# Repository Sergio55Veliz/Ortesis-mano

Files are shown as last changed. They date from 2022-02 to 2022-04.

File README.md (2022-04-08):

# Ortesis dinámica extensora de mano
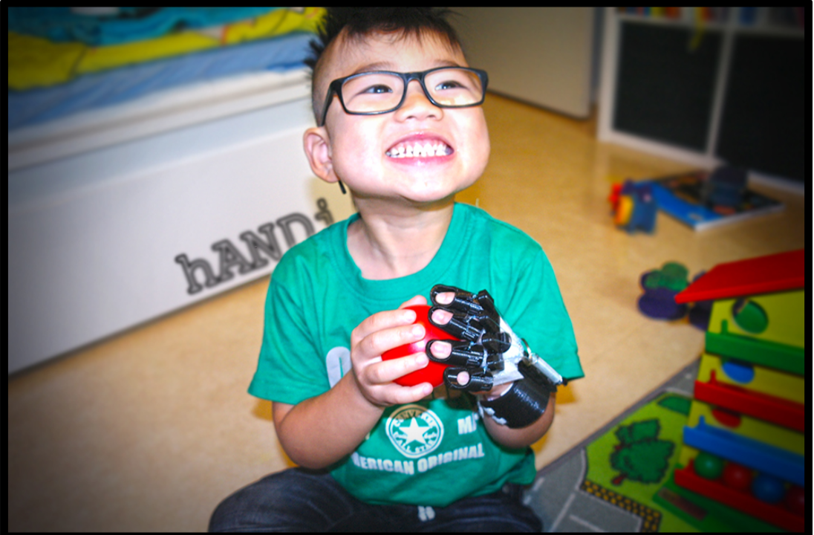
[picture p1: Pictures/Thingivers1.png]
niño

En este repositorio se encuentra la parametrización de una órtesis dinámica extensora para la movilidad de las manos.
El diseño de este sistema esta dirigido a personas con problemas  en las articulaciones o tendones que les impida abrir las manos pero si tengan la capacidad de cerrarlas.
El diseño se lo obtuvo de [Thingiverse](https://www.thingiverse.com/thing:1064647) en el repositorio del usuario Emanuel Teljemo.

# Softwares
Se usaron dos softwares. 
 - `OpenScad`: Un software libre para creación de objetos sólidos CAD por medio de programación, gracias a la programación tenemos control total del diseño de la pieza y podemos crear funciones que dependiendo de lo que se le ingresa, nos da como salida piezas de diferentes medidas.
Esto lo aprovechamos para que al final del desarrollo del código se puedan simplemente ingresar ciertas medidas específicas que debe de tener el sistema para adaptarse a su usuario, siendo así que no hay que diseñar TODO de nuevo para cada paciente. 
 - `Cura`: Programa usado para impresión 3D. Este permite ciertos parámetros de impresión para que puedan ser transformados en código G.

# Funcionamiento
La órtesis permite el movimiento de mano para personas que tienen problemas con abrirla. Esto lo hace gracias a que se usan resortes que sirven para regresar la mano al estado de completamente abierta.
En este caso se usan solamente dos resortes, uno para el pulgar y otro para los demás dedos.

# Materiales

| Elemeto | Cantidad | Figura |
| :--- | :---: | :---: |
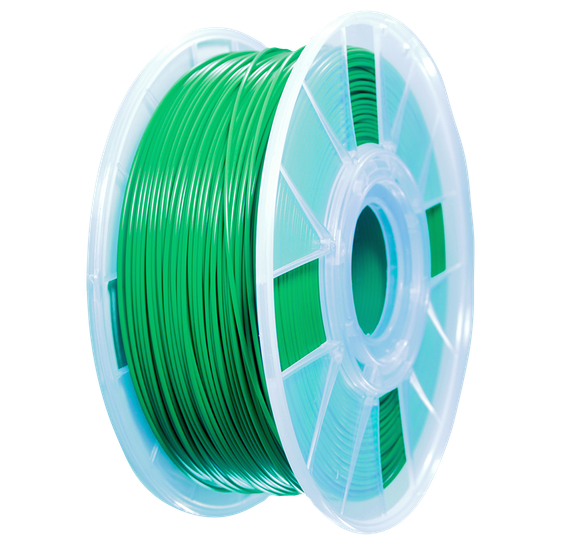
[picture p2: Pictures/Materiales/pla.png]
PLA
| Filamento PLA | 1 |  |
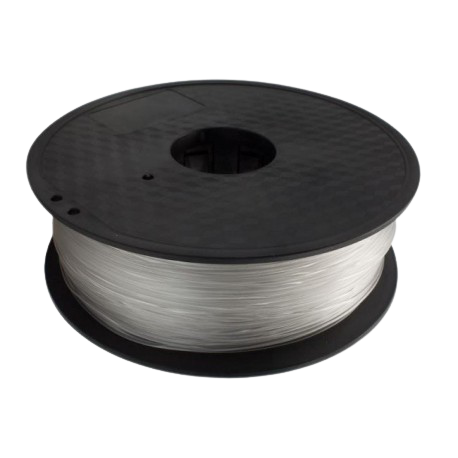
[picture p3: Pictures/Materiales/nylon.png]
nylon
| Hilo de Nylon (no elástico) | 1 |  |
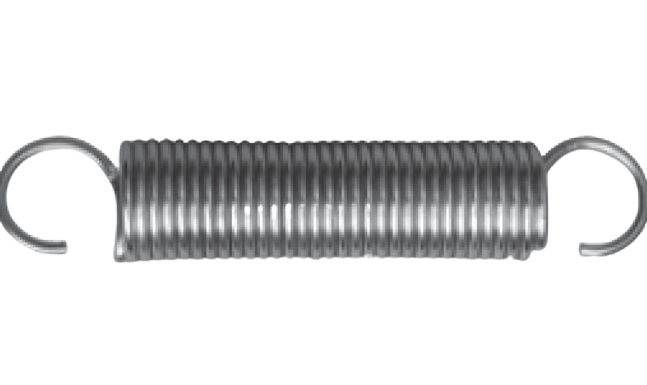
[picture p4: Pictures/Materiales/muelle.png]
muelle
| Resorte o muelle | 2 |  |
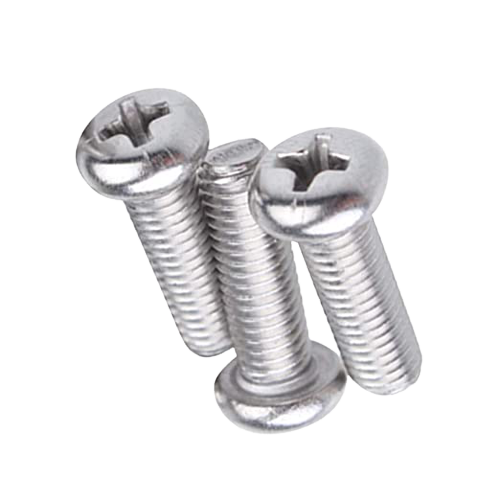
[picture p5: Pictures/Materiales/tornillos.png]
tornillos
| Tornillo M5x10mm <br> Tornillo M5x25mm <br>y sus respectivas tuercas | 6 <br>2 <br> ... |  |
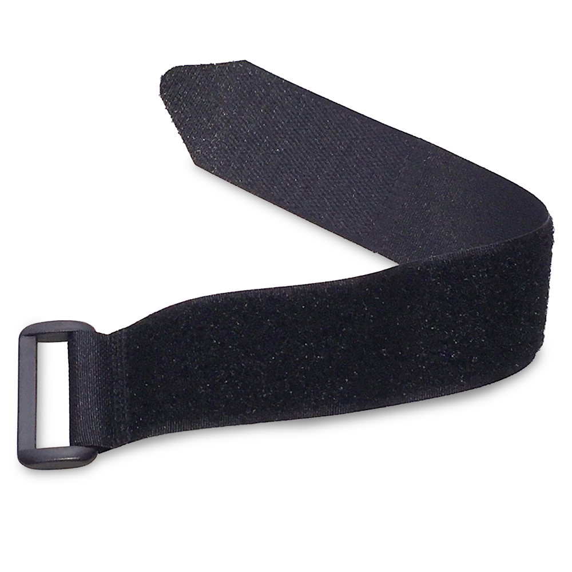
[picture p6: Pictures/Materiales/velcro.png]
velcro
| Velcro | 1 |  |
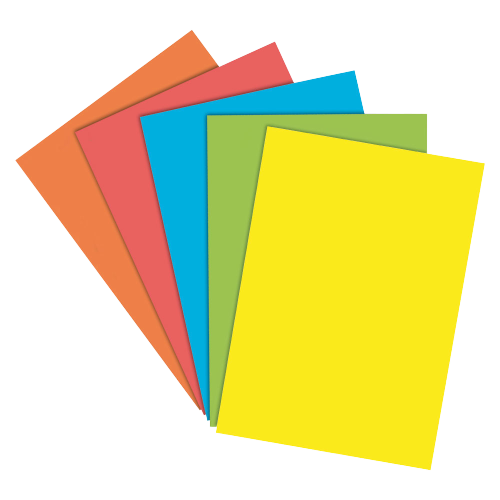
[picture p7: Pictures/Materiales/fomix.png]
fomix
| Fomix | 1 |  |

# Medidas del Paciente
Para la generación de la órtesis en el software OpenScad, se necesitan 7 medidas del antebrazo y mano. A continuación, se hablará de cada una de ellas.

<div align="center">
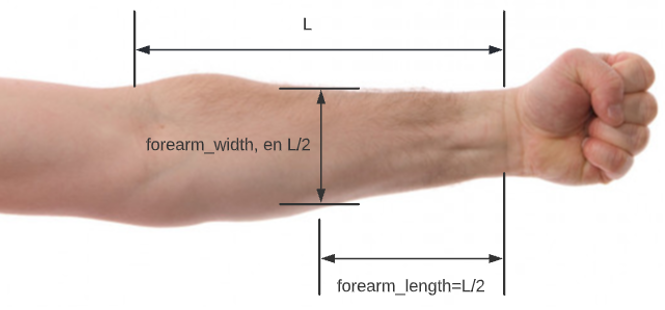
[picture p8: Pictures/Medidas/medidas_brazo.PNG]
medidas_brazo
    
    <p>
        <i>Medidas del antebrazo</i>
    </p>
</div>

Para empezar, se explicarán las dos primeras variables correspondientes a las medidas del antebrazo, como se observa en la figura anterior, se tiene que la variable `forearm_length` es la mitad de la longitud del antebrazo, es decir, L/2. Luego se tiene que `forearm_width` es el ancho del antebrazo, cabe recalcar que dicho ancho será medido en L/2, esto es de suma importancia ya que el antebrazo no tiene un ancho uniforme a lo largo del mismo.

Como recomendación se tiene que a la variable `forearm_width` se le debe sumar 10-12 milímetros aproximadamente (offset) debido a que se utiliza fómix en una pieza para que no lastime la piel del usuario, de forma que reduce el diámetro inicial.

<div align="center">
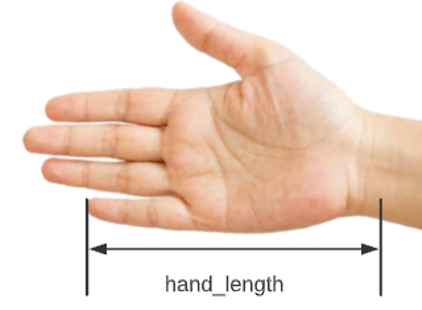
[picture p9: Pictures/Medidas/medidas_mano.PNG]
medidas_mano
    
    <p>
        <i>Medidas de la mano</i>
    </p>
</div>

Para la mano se tendrá una sola variable, la cual se llamará `hand_length`, esta será medida desde la muñeca hasta la parte superior o tope del dedo meñique como se observa en la figura anterior.

<div align="center">
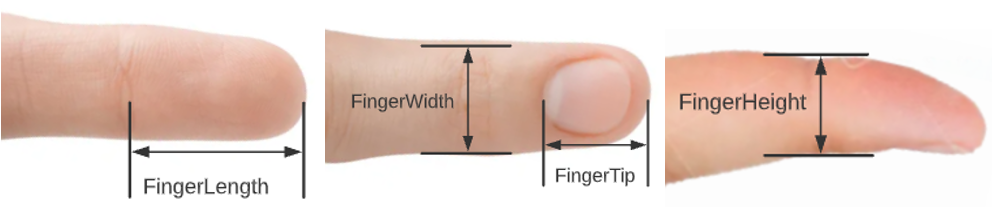
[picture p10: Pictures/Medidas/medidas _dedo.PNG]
medidas_dedo
    
    <p>
        <i>Medidas del dedo</i>
    </p>
</div>

Como se puede observar en la figura anterior, para los dedos se tienen 4 medidas:

- `FingerLength` es medido desde el inicio de la falange distal hasta la punta del dedo
- `FingerWidth` es el ancho del dedo en la zona de la articulación interfalángica distal
- `FingerTip` es medido desde el nacimiento de la uña hasta la punta del dedo
- `FingerHeight` es el alto del dedo en la zona de la articulación interfalángica distal

Cabe recalcar que este proceso de medición se debe de realizar para los cinco dedos de la mano.

# Piezas generadas
Las piezas a generar son 11:
| Pieza | Descripción | Cantidad | Figura |
| :--- | :--- | :---: | :---: |
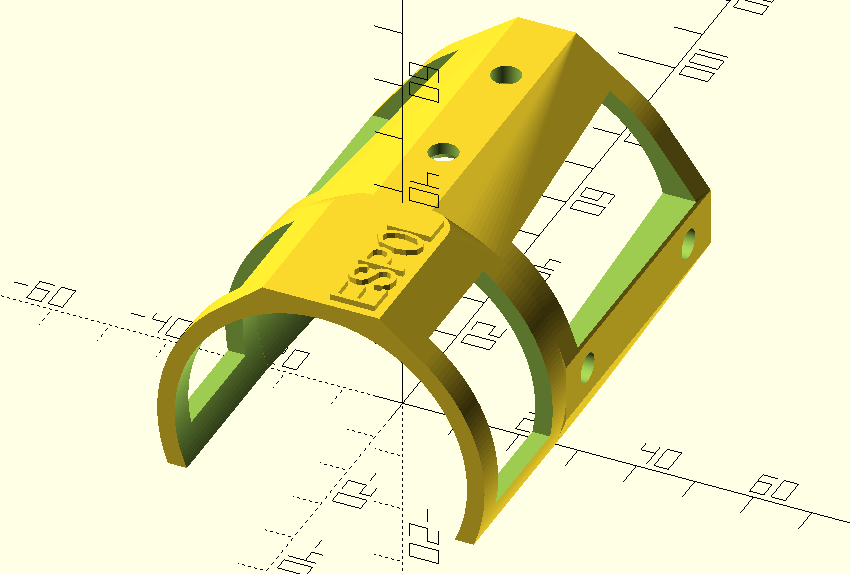
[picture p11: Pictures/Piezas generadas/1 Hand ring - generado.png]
pieza1
| [Hand ring](ortesis_openscad/ORTESIS.scad#L55) | - | 1 |  |
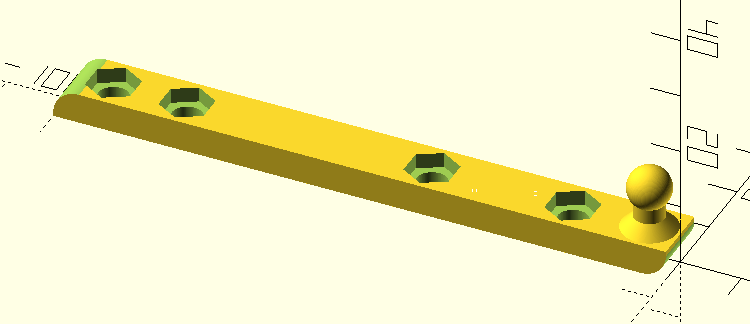
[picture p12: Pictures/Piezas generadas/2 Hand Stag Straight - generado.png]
pieza2
| [Hand Stag Straight](ortesis_openscad/ORTESIS.scad#L263) | - | 1 |  |
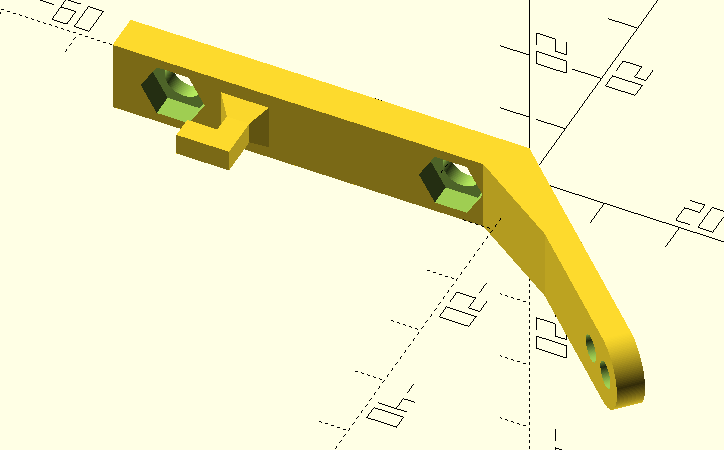
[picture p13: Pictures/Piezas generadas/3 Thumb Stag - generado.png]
pieza3
| [Thumb Stag](ortesis_openscad/ORTESIS.scad#L444) | - | 1 |  |
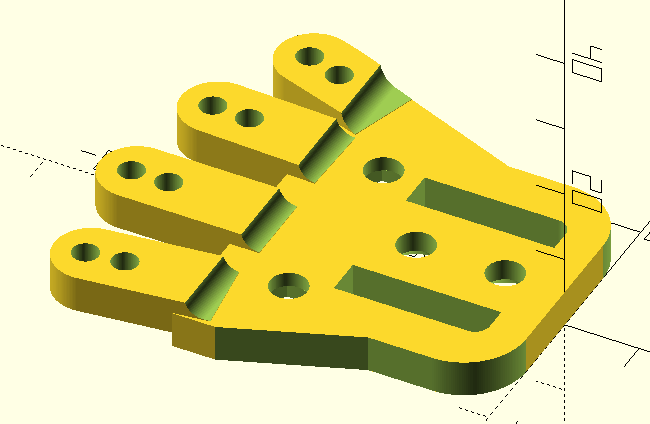
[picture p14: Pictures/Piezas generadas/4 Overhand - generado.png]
pieza4
| [Overhand](ortesis_openscad/ORTESIS.scad#L221) | - | 1 |  |
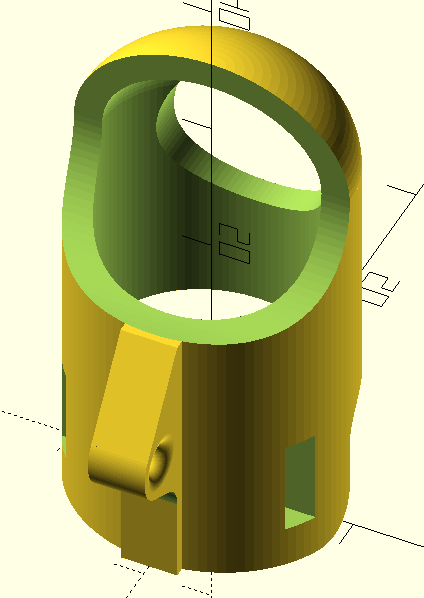
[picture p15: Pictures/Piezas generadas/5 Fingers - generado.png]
pieza5
| [Fingers](ortesis_openscad/ORTESIS.scad#L532) | - | 5 |  |
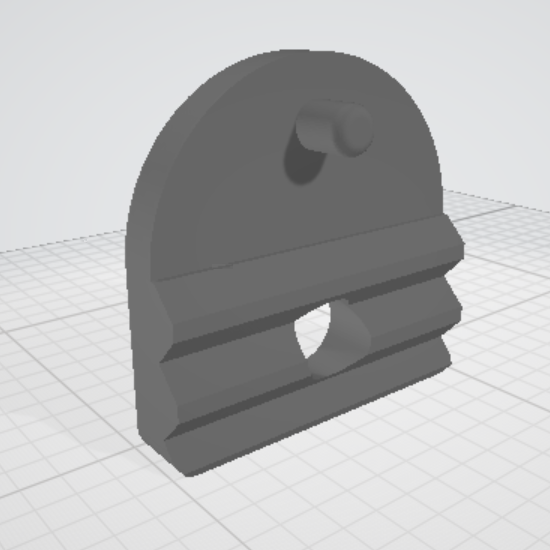
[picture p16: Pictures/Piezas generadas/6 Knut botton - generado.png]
pieza6
| [Knut botton](ortesis_openscad/Knut_1_0_bottom_m4nut.stl) | - | 1 |  |
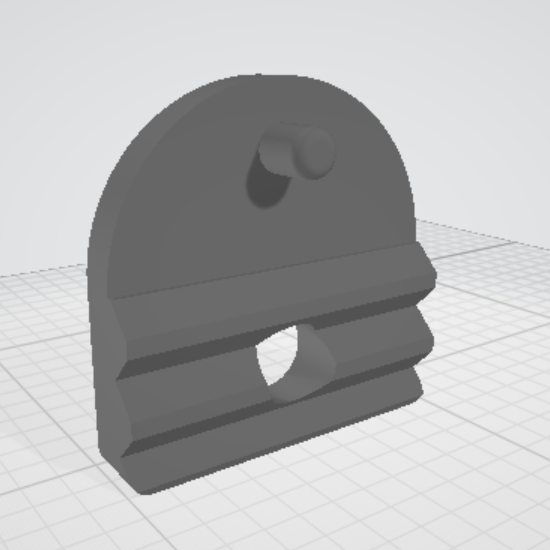
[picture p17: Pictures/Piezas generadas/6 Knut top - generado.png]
pieza7
| [Knut top](ortesis_openscad/Knut_1_0_top_plug4mm.stl) | - | 1 |  |

Como vemos en la tabla, las primeras 5 piezas mencionadas las podemos obtener del archivo OpenScad que programamos, pero las últimas 2 piezas no son parametrizadas. Esas son piezas que no deben de ser modificadas proporcionadas por 
Emanuel Teljemo de su repositorio en [Thingiverse](https://www.thingiverse.com/thing:1064647).

Para generar las piezas, Se deben de seguir los siguientes pasos:
 1. Tomarle las medidas necesarias al paciente e ingresar los parámetros especificados en el archivo `ORTESIS.scad` desde la [línea 13 a la 34](ortesis_openscad/ORTESIS.scad#L13)
 2. Especificar si es para la mano derecha o la izquierda [(línea 10)](ortesis_openscad/ORTESIS.scad#L10)
 3. Especificar qué pieza se quiere generar [(línea 6)](ortesis_openscad/ORTESIS.scad#L6)
 4. Repetir el 3er paso para todas las piezas.

# Configuración del Software de impresión
Se utilizó el software Cura para la impresión, pero básicamente todos se pueden configurar con los mismos parámetros especificados. Los parámetros de impresión utilizados para la impresión son los siguientes:

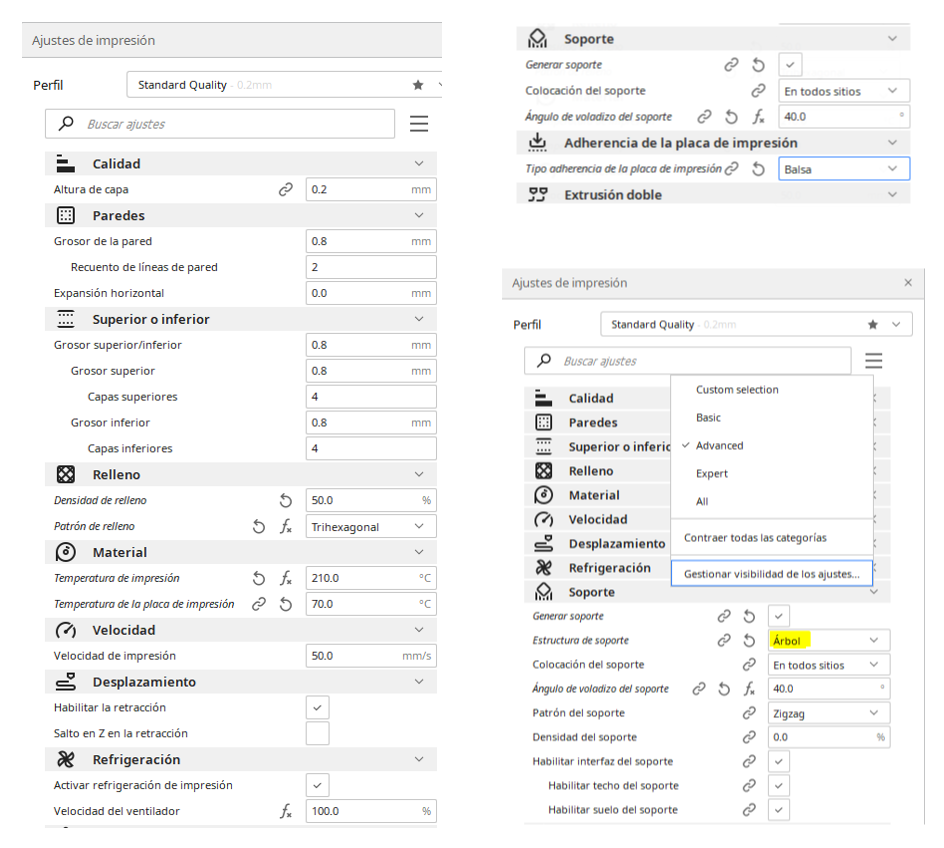
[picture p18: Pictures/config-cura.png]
conf_cura


<br><br><br>

# Ensamblaje del las piezas impresas

# Recomendaciones
 - Para la **generación del archivo STL** de la pieza **‘hand ring’** se debe de aumentarle un offset ya que se utiliza fómix en el interior de dicha pieza para que no lastime la piel del usuario, lo que causa que el diámetro inicial sea menor. El valor recomendado es de 10 a 12 mm de más.
 - **Para** la realizar la **compra del resorte**, se debe de tener en cuenta que la fuerza y largo de dicho resorte debe ser el apropiado para el usuario. De forma general, para manos grandes se necesita más fuerza y largo, y para manos pequeñas se utiliza resortes no tan fuertes y no tan largos. Si se utilizan resortes en los que se deba de aplicar demasiada fuerza esto puede generar que se le corte la circulación al paciente.
 - Para colocar los **hilos de nylon** en la órtesis, se debe de cortar de forma correcta el largo de los hilos, ya que si es muy largo no podrá estirar los dedos, y si es muy corto, los estirará mucho.
 - Es importante verificar que los **tornillos lleguen al tope** de la unión de dos piezas, debido a que los resortes pueden chocar con el exceso del tornillo si este es muy largo, por ende, se recomienda utilizar tornillos de 5 mm de diámetro y 10 mm de alto, a excepción de la pieza ‘Knut’.
 - Se recomienda cambiar el tipo de soporte convencional a tipo árbol para la **impresión de los Fingers** ya que facilita el despegue del material de soporte.
 - Para la **medición e impresión de los dedos**, será un proceso iterativo debido a que cada persona tiene diferentes tipos de dedos (anchos, flacos, largos), por eso, es importante mencionar que cada dedo tendrá un **offset** en particular para que al usuario no le quede ni tan suelto o ajustado. Se recomienda sumarle entre 1 y 1.5 mm a las medidas que uno realiza y seguir iterando hasta tener las medidas correctas.
 - Se recomienda utilizar un calibrador vernier para medir las variables necesarias para la creación de la órtesis, en la medición de la longitud del largo del antebrazo (L) se puede utilizar una cinta métrica o una regla de 30 cm si es posible. En caso de usar el calibrador, es mejor si tiene acoplado un material para alargar la mordaza fija, esto permitiría medir de mejor forma el largo de los dedos.

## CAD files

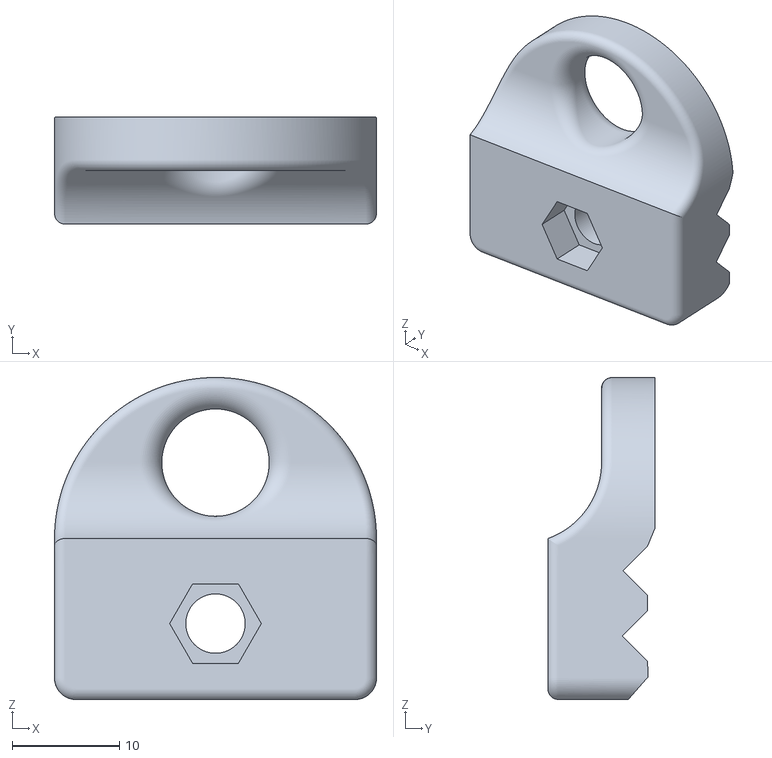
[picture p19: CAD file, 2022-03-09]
Knut_1_0_bottom_m4nut.stl
30.0 x 10.0 x 30.0

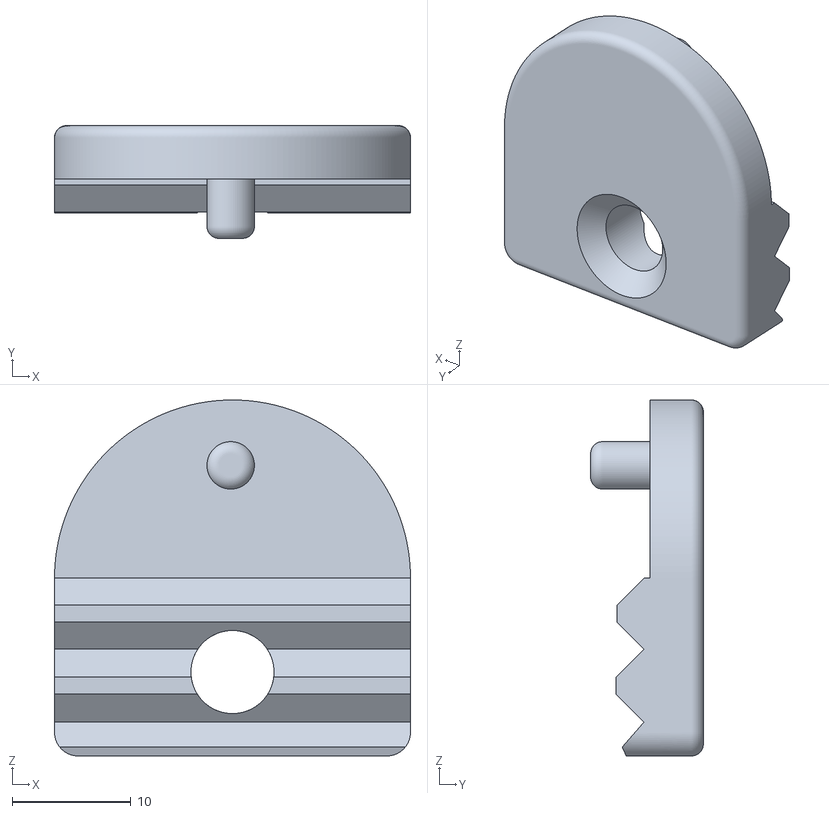
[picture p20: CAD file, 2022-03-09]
Knut_1_0_top_plug4mm.stl
30.0 x 9.50 x 30.0

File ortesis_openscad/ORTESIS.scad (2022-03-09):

//Se importa una librería para colocar nombres en el sólido
use <write.scad>

//Puede escribir las siguientes opciones:
//Número 1: soporte antebrazo, Número 2: soporte mano, Número 3: mano, Número 4: soporte pulgar, Número 5: dedo   
pieza= 1;

//Puede escribir las siguientes opciones para el tipo de brazo-mano:
//derecha, izquierda
mano="derecha";
// Unidades [mm] 

// mitad de la longitud del antebrazo
forearm_length=83; //min valor 83mm

//ancho del antebrazo, generalmente es medido en la mitad de la longitud del antebrazo
forearm_width=50; //min valor 50mm



//Longitud medida desde la muñeca hasta el tope del dedo meñique
hand_length=77; //Valor min 77

//Ancho del dedo
FingerWidth = 15.5;
//Alto del dedo
FingerHeight = 13.5;
//largo del dedo
FingerLength = 23.5;
//Largo del orificio de la uña del dedo
FingerTip = 12;

//Grosor del material para los dedos, valor recomendado!!!
Thikness = 2;




ancho_forearm_p=forearm_width/50;
valor1=hand_length/1.73033707865;
valor_p=valor1/44.5;

//largo de la parte donde se coloca el nombre "ESPOL"
largo1=round(forearm_length/2.77);

//Largo de la parte que va a ir con los tornillos
largo2=forearm_length-largo1;

valor=largo2/0.95495495495;
//El desfase vertical es la distancia que se eleva el sólido ya que no es semi-circunferencia para tener un "mejor" agarre
desfase_vertical= forearm_width/5;


//********************************************************
// Código del soporte del antebrazo

// Sólido donde se coloca el nombre
module soporte_nombre(){
    difference(){
        translate([0,-largo1/2, (forearm_width+6)/2 +desfase_vertical-forearm_width/50])
        cube([forearm_width/2.5,largo1,forearm_width/25],center=true);
            
        translate([-forearm_width/5,0,(forearm_width+6)/2 +desfase_vertical-forearm_width/25])
        empalme(5,forearm_width/10,0,0,0);
            
        translate([forearm_width/5,0,(forearm_width+6)/2 +desfase_vertical-forearm_width/25])
        rotate([0,0,270])
        empalme(5,forearm_width/10,0,0,0);
    }
}

// Primer Soporte del antebrazo (donde se coloca el nombre "ESPOL")
module soporte1(){
    difference(){
        hull(){
            translate([0,0,desfase_vertical])
            rotate([90,0,0])
            cylinder(h=largo1,d=forearm_width+6,$fn=200);
                
            soporte_nombre();
        }  
        translate([0,0.5,desfase_vertical])
        rotate([90,0,0])
        cylinder(h=largo1+1,d=forearm_width,$fn=200);
            
        translate([0,-largo1/2,forearm_width/2.63])
        cube([forearm_width+20,largo1/1.5,forearm_width/1.79],center=true);
    }
    translate([forearm_width/5 -1.5,-largo1+1.5,(forearm_width+6)/2 +desfase_vertical])
    rotate([0,0,90])
    write("ESPOL",t=1,h=largo1/4);
}


// Con difference se puede hacer empalme a un solido
module empalme(radio,largo,inclinacionX,inclinacionY,inclinacionZ){
    diam=radio*2;
    scale([1.05,1.05,1.05])
    translate([radio,-radio,0])
    rotate([inclinacionX,inclinacionY,inclinacionZ])
    linear_extrude(largo){
        difference(){
            square(diam,center=true);
            circle(d=diam,$fn=200);
            scale([1.1,1.1,1.1])
            polygon(points=[[0,radio],[radio,radio],[radio,-radio],[-radio,-radio],[-radio,0],[0,0]]);
        }
    }
}



// Empalme 2. Por el momento no se lo utiliza en este proyecto
module empalme2(diam, diam_circ){
    //Cambiar el valor 10
    translate([0,diam/2,10])
    rotate([90,0,0])
    rotate_extrude($fn=150)
    translate([diam_circ/2+diam/2,0,0])
    union(){
        polygon(points=[[0,diam/2],[diam/2,diam/2],[diam/2,-diam/2
            ],[-diam/2,-diam/2],[-diam/2,0],[0,0]]);
        circle(d=diam,$fn=150);
    }
}

// Soporte para colocar los tornillos laterales
module agarres_laterales(){
    difference(){
        translate([-(forearm_width+6)/2,0,forearm_width/10])
        cube([4,largo2,desfase_vertical]);
        translate([-(forearm_width+6)/2+2,0,forearm_width/10])
        cube([4,largo2/2,desfase_vertical]);
    }
}

// Soporte para colocar los tornillos superiores
module agarre_superior(){
    difference(){
        translate([0,largo2/2,(forearm_width+6)/2 +desfase_vertical-2.5])
        rotate([0,90,0])
        cube([5,largo2,desfase_vertical],center=true);
        translate([0,largo2/2,(forearm_width+6)/2 +desfase_vertical-5])
        rotate([0,90,0])
        cube([5,largo2,desfase_vertical],center=true);
    }
}

// Huecos para los tornillos
module huecos_tornillos(inclinacionX,inclinacionY,inclinacionZ){
    rotate([inclinacionX,inclinacionY,inclinacionZ])
    union(){
        translate([0,0,2])
        cylinder(h=5,d=5,$fn=200);
        cylinder(h=2.1,d1=9,d2=5,$fn=200);
    }
}

// Se colocan los huecos de los tornillos en las partes laterales
module huecos_laterales(){
    translate([forearm_width/2 -0.9,largo2/6.752,desfase_vertical])
    huecos_tornillos(0,90,0);
    translate([forearm_width/2 -2.8,largo2/1.183,desfase_vertical])
    huecos_tornillos(0,90,0);
}

// Se colocan los huecos de los tornillos en la parte superior
module huecos_superiores(){
    translate([0,largo2/3.533,forearm_width/2 +desfase_vertical-1.2])
    huecos_tornillos(0,0,0);
    translate([0,largo2/1.3947,forearm_width/2 +desfase_vertical-2.3])
    huecos_tornillos(0,0,0);
}

//Segundo Soporte donde se colocan los tornillos, todas las anteriores funciones unidas
module soporte2(){
    difference(){
        union(){
            difference(){
                hull(){
                    rotate([90,0,0])
                    translate([0,desfase_vertical,-largo2/2])
                    cylinder(h=largo2,d2=forearm_width+6,d1=forearm_width+1,$fn=200, center=true);
                    agarre_superior();
                    agarres_laterales();
                    mirror([1,0,0])
                    agarres_laterales();
                }
                rotate([90,0,0])
                translate([0,desfase_vertical,-largo2/2])
                cylinder(h=largo2 +1,d2=forearm_width,d1=forearm_width-5,$fn=200, center=true);
                    
                translate([0,largo2/2,forearm_width/2.08])
                cube([forearm_width+20,largo2-9.52,forearm_width/3],center=true);   
            }
        }
        huecos_laterales();
        mirror([1,0,0])
        huecos_laterales();
        huecos_superiores();
    }
}


//Ensamble de la pieza final
module soporte_antebrazo(){
    difference(){
        union(){
            soporte1();
            soporte2();
        }
        translate([0,0,-forearm_width/5])
        cube([forearm_width+10,forearm_length+100,forearm_width/2.5],center=true); 
    }
}




//********************************************************
//Código soporte mano

module base_soporte(largo,ancho, espesor){
    scale([1,ancho_forearm_p,1])    
    translate([-largo/2,0,espesor/2])
    cube([largo,ancho,espesor],center=true);
}

module soporte_resorte(){
    union(){ 
        translate([0,0,2])
        cylinder(h=5,d=5,$fn=200);
        cylinder(h=2.1,d1=9,d2=5,$fn=200);
        translate([0,0,7])
        sphere(d=7,$fn=120);
    }
}

module soporte_tuerca(){
    rotate([0,0,90])
    union(){
        cylinder(h=2.5,d=8.5,$fn=6,center=true);
        cylinder(h=20,d=5,$fn=120,center=true);
    }
}

module empalme(radio,largo,inclinacionX,inclinacionY,inclinacionZ){
    diametro=radio*2;
    translate([0,0,-1])
    scale([1.05,1.05,1.05])
    translate([radio,-radio,0])
    rotate([inclinacionX,inclinacionY,inclinacionZ])
    linear_extrude(largo){
        difference(){
            square(diametro,center=true);
            circle(d=diametro,$fn=200);
            scale([1.1,1.1,1.1])
            polygon(points=[[0,radio],[radio,radio],[radio,-radio],[-radio,-radio],[-radio,0],[0,0]]);
        }
    }
}

module hand_stag_straight(){
    difference(){
        union(){
            base_soporte(valor,10,5);
            translate([-valor,0,0])
            base_soporte(valor1,10,5);
            translate([-5,0,5])
            soporte_resorte();
        }
        translate([-8.4,-25,5.2])
        empalme(4,50,90,270,180);

        mirror([1,0,0])
        translate([-8.4+valor+valor1,30,1.8])
        empalme(4,50,90,90,0);

        translate([-valor/3.171428571,0,3.75])
        soporte_tuerca();
        translate([-valor/1.37037037,0,3.75])
        soporte_tuerca();

        translate([-valor-valor1/1.78,0,3.75])
        soporte_tuerca();
        translate([-valor-valor1/1.202702703,0,3.75])
        soporte_tuerca(); 
    }
}


//********************************************************
//Código mano
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

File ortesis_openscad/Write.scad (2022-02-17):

/* 	Version 3
	Added support for font selection (default is Letters.dxf)
	Added WriteCube module
	Added Rotate for text (rotates on the plane of the text)
	Added writesphere
	Added space=     (spacing between characters in char widths) def=1
	Added writecylinder()

 By Harlan Martin
 harlan@sutlog.com
 January 2012

 (The file TestWrite.scad gives More usage examples)
 (This module requires the file Letters.dxf to reside in the same folder)
 (The file Letters.dfx was created with inkscape..Each letter is in its own layer)
 (This module seperates each letter in the string and imports it from Letters.dfx)
 
*/

	pi=3.1415926535897932384626433832795028841971693993751058209;
	pi2=pi*2;


// These control the default values for write() writesphere() writecube()
// if the parameters are not included in the call. Feel free to set your own
// defaults.

//default settings
	center=false;
	h = 4;			 //mm letter height
	t = 1; 			//mm letter thickness
	space =1; 			//extra space between characters in (character widths)
	rotate=0;			// text rotation (clockwise)
	font = "Letters.dxf";	//default for aditional fonts


// write cube defaults
	face = "front";	 // default face (top,bottom,left,right,back,front)
	up =0;		 //mm up from center on face of cube
	down=0;
	right =0;		 //mm left from center on face of cube
	left=0;		
	

// write sphere defaults
	rounded=false;	 //default for rounded letters on writesphere
	north=0; 		// intial text position (I suggest leave these 0 defaults)
	south=0;
	east=0;
	west=0;
	spin=0;
// writecylinder defaults
	middle=0;     //(mm toward middle of circle)
	ccw=false;   //write on top or bottom in a ccw direction
 	r1=0; 	//(not implimented yet)
	r2=0;	 	//(not implimented yet)
	


// Contact me if your interested in how to make your own font files
// Its tedious and time consuming, but not very hard


module writecylinder(text,where,radius,height){
	wid=(.125* h *5.5 * space);
	widall=wid*(len(text)-1)/2; 
	//angle that measures width of letters on sphere
	function NAngle(radius)=(wid/(pi2*radius))*360;
	//angle of half width of text
	function mmangle(radius)=(widall/(pi2*radius)*360);
	
	if ((face=="top")||(face=="bottom") ){
		if (face=="top" ){
			if (center==true){
				writecircle(text,where+[0,0,height/2],radius-h,rotate=rotate,font=font,h=h,t=t,
				space=space,east=east,west=west,middle=middle,ccw=ccw);
			}else{
				writecircle(text,where+[0,0,height],radius-h,rotate=rotate,font=font,h=h,t=t,
				space=space,east=east,west=west,middle=middle,ccw=ccw);
			}
		}else{
			rotate(180,[1,0,0])
			if (center==true){
				writecircle(text,where+[0,0,height/2],radius-h,rotate=rotate,font=font,h=h,t=t,
				space=space,east=east,west=west,middle=middle,ccw=ccw);
			}else{
				writecircle(text,where+[0,0,0],radius-h,rotate=rotate,font=font,h=h,t=t,
				space=space,east=east,west=west,middle=middle,ccw=ccw);
			}
		}
	
	}else{
        if (center==true)  {
            rotate(-mmangle(radius)*(1-abs(rotate)/90),[0,0,1])
            translate(where)
            writethecylinder(text,where,radius,height,r1=radius,r2=radius,h=h,
                rotate=rotate,t=t,font=font,face=face,up=up,down=down,
                east=east,west=west,center=center,space=space,rounded=rounded);
        } else{
            rotate(-mmangle(radius)*(1-abs(rotate)/90),[0,0,1])
            translate(where+[0,0,height/2])
                writethecylinder(text,where,radius,height,r1=radius,r2=radius,h=h,
                rotate=rotate,t=t,font=font,face=face,up=up,down=down,
                east=east,west=west,center=center,space=space,rounded=rounded);
        }
	}
}
module writecircle(text,where,radius){
	wid=(.125* h *5.5 * space);
	widall=wid*(len(text)-1)/2;
	//angle that measures width of letters on sphere
	function NAngle(radius)=(wid/(pi2*radius))*360;
	//angle of half width of text
	function mmangle(radius)=(widall/(pi2*radius)*360);	
	
	if (ccw==true){
		rotate(-rotate+east-west,[0,0,1]){
			rotate(-mmangle(radius-middle),[0,0,1]){
			translate(where)
				for (r=[0:len(text)-1]){
					rotate(-90+r*NAngle(radius-middle),[0,0,1]) // bottom out=-270+r 
					translate([radius-middle,0,0])
					//rotate(90,[1,0,0])
					//rotate(90,[0,1,0])
					rotate(-270,[0,0,1])  // flip text (botom out = -270)
					write(text[r],center=true,h=h,t=t,font=font);
				}
			}
		}
	}else{
		rotate(-rotate-east+west,[0,0,1]){
			rotate(mmangle(radius-middle),[0,0,1]){
			translate(where)
				for (r=[0:len(text)-1]){
					rotate(90-r*NAngle(radius-middle),[0,0,1]) // bottom out=-270+r 
					translate([radius-middle,0,0])
					//rotate(90,[1,0,0])
					//rotate(90,[0,1,0])
					rotate(270,[0,0,1])  // flip text (botom out = -270)
					write(text[r],center=true,h=h,t=t,font=font);
				}
			}
		}		
	}

}
module writethecylinder(text,where,radius,height,r1,r2){
	wid=(.125* h *5.5 * space);
	widall=wid*(len(text)-1)/2; 
	//angle that measures width of letters on sphere
	function NAngle(radius)=(wid/(pi2*radius))*360*(1-abs(rotate)/90);
	//angle of half width of text

	function mmangle(radius)=(widall/(pi2*radius)*360);
			translate([0,0,up-down])
			rotate(east-west,[0,0,1])
			for (r=[0:len(text)-1]){
				rotate(-90+(r*NAngle(radius)),[0,0,1])
				translate([radius,0,-r*((rotate)/90*wid)+(len(text)-1)/2*((rotate)/90*wid)])
				rotate(90,[1,0,0])
				rotate(90,[0,1,0])
				write(text[r],center=true,h=h,rotate=rotate,t=t,font=font);
		//echo("zloc=",height/2-r*((rotate)/90*wid)+(len(text)-1)/2*((rotate)/90*wid));
			}

}


module writesphere(text,where,radius){
	wid=(.125* h *5.5 * space);
	widall=wid*(len(text)-1)/2;
	
	echo("-----------------",widall,wid,mmangle(radius));
	//angle that measures width of letters on sphere
	function NAngle(radius)=(wid/(pi2*radius))*360;
	//angle of half width of text
	function mmangle(radius)=(widall/(pi2*radius)*360);	

	rotate(east-west,[0,0,1]){
	rotate(south-north,[1,0,0]){
	rotate(spin,[0,1,0]){
	rotate(-mmangle(radius),[0,0,1]){
		if ( rounded== false ){
			translate(where)
			for (r=[0:len(text)-1]){
				rotate(-90+r*NAngle(radius),[0,0,1])
				translate([radius,0,0])
				rotate(90,[1,0,0])
				rotate(90,[0,1,0])
				write(text[r],center=true,h=h,rotate=rotate,t=t,font=font);
			}
		}else{
			difference(){
				translate(where)
				for (r=[0:len(text)-1]){
					rotate(-90+r*NAngle(radius),[0,0,1])
					translate([radius,0,0])
					rotate(90,[1,0,0])
					rotate(90,[0,1,0])
					write(text[r],center=true,h=h,rotate=rotate,t=t*2+h,font=font);
				}
				difference(){ //rounded outside
					sphere(radius+(t*2+h)*2);
					sphere(radius+t/2);
				}
				sphere(radius-t/2); // rounded inside for indented text
			} 
		}
	}}}}
}


module writecube(text,where,size){
	if (str(size)[0] != "["){  
		// its a square cube (size was not a matrix so make it one)
		writethecube(text,where,[size,size,size],h=h,rotate=rotate,space=space,
		t=t,font=font,face=face,up=up,down=down,right=right,left=left);

	}else{
		// its not square
		writethecube(text,where,size,h=h,rotate=rotate,space=space,
		t=t,font=font,face=face,up=up,down=down,right=right,left=left);
	}
}
// I split the writecube module into 2 pieces.. easier to add features later
module writethecube(text,where,size){
		if (face=="front") {
			translate([where[0]+right-left,where[1]-size[1]/2,where[2]+up-down])
			rotate(90,[1,0,0])
			write(text,center=true,h=h,rotate=rotate,t=t,font=font);
		}
		if (face=="back") {
			translate([where[0]+right-left,where[1]+size[1]/2,where[2]+up-down])
			rotate(90,[1,0,0])   // rotate around the x axis
			rotate(180,[0,1,0])  // rotate around the y axis (z before rotation)
			write(text,center=true,h=h,rotate=rotate,t=t,font=font);
		}
		if (face=="left") {
			translate([where[0]-size[0]/2,where[1]-right+left,where[2]+up-down ])
			rotate(90,[1,0,0])   // rotate around the x axis
			rotate(90,[0,-1,0])  // rotate around the y axis  (z before rotation)
			write(text,center=true,h=h,rotate=rotate,t=t,font=font);
		}
		if (face=="right") {
			translate([where[0]+size[0]/2,where[1]+right-left,where[2] +up-down])
			rotate(90,[1,0,0])   // rotate around the x axis
			rotate(90,[0,1,0])  // rotate around the y axis  (z before rotation)
			write(text,center=true,h=h,rotate=rotate,t=t,font=font);
		}
		if (face=="top") {
			translate([where[0]+right-left,where[1]+up-down,where[2]+size[2]/2 ])
			write(text,center=true,h=h,rotate=rotate,t=t,font=font);
		}
		if (face=="bottom") {
			translate([where[0]+right-left,where[1]-up+down,where[2]-size[2]/2 ])
			rotate(180,[1,0,0])
			write(text,center=true,h=h,rotate=rotate,t=t,font=font);
		}
}
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

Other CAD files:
ortesis_openscad/Letters.dxf

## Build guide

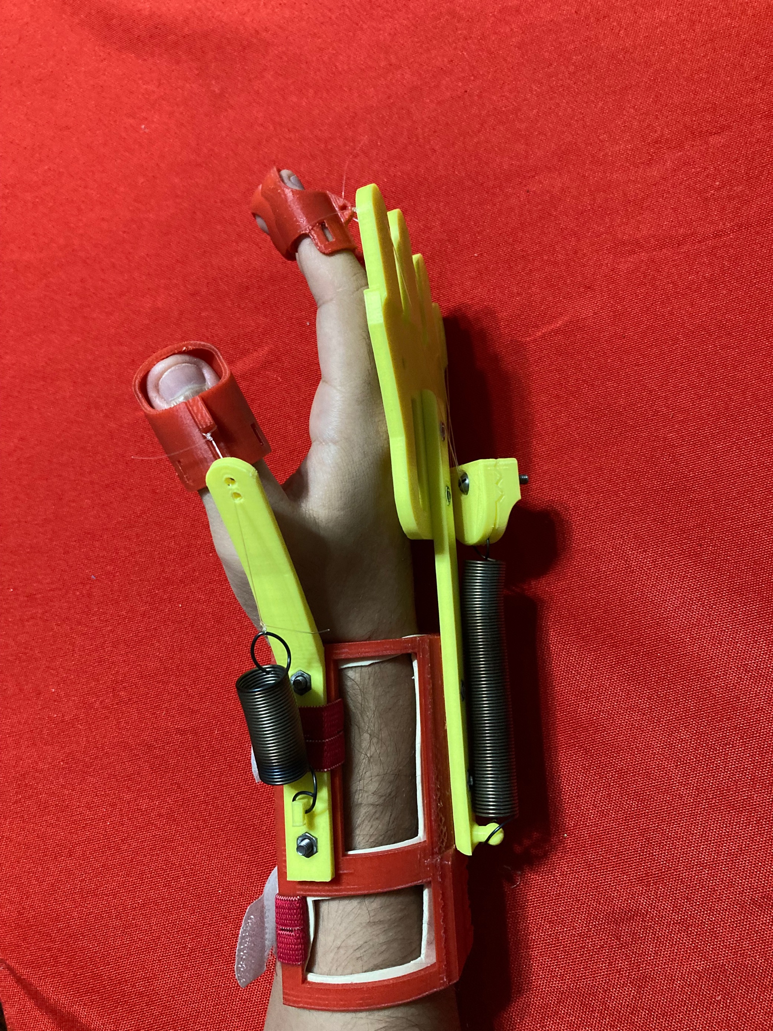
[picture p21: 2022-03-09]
Pictures/Ensamble/Vista lateral - estirado.png

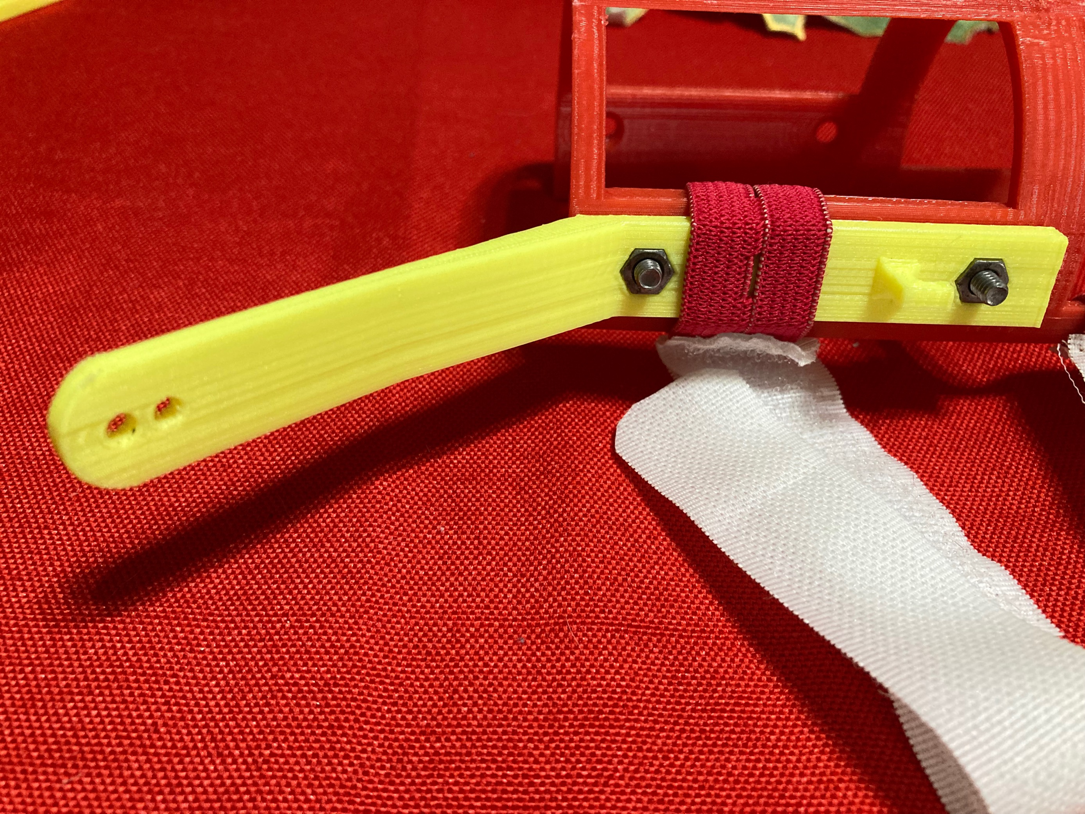
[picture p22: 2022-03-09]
Pictures/Ensamble/1.png

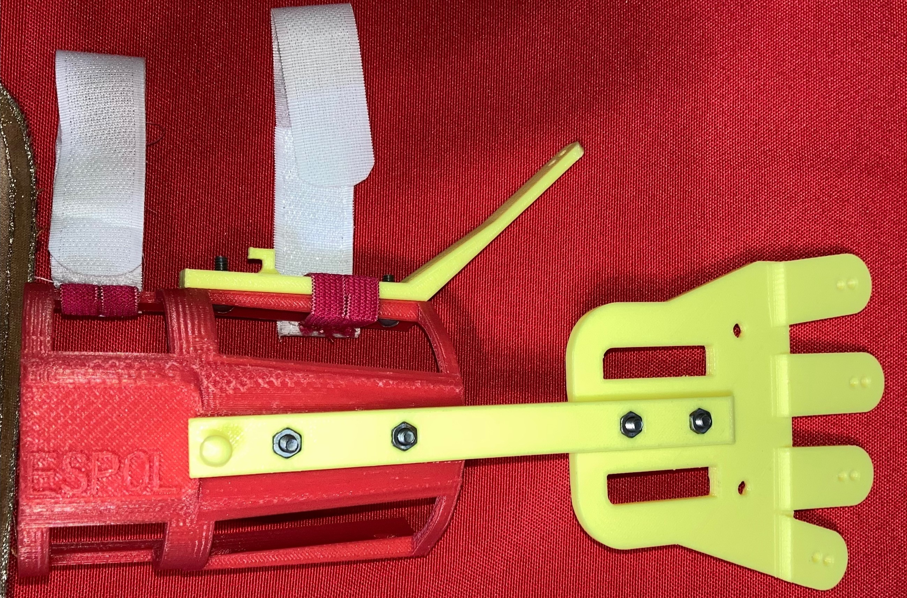
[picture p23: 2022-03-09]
Pictures/Ensamble/5.png

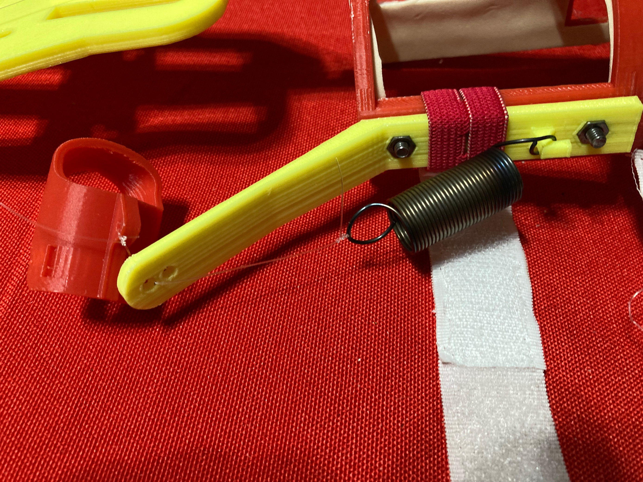
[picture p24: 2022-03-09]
Pictures/Ensamble/10.png

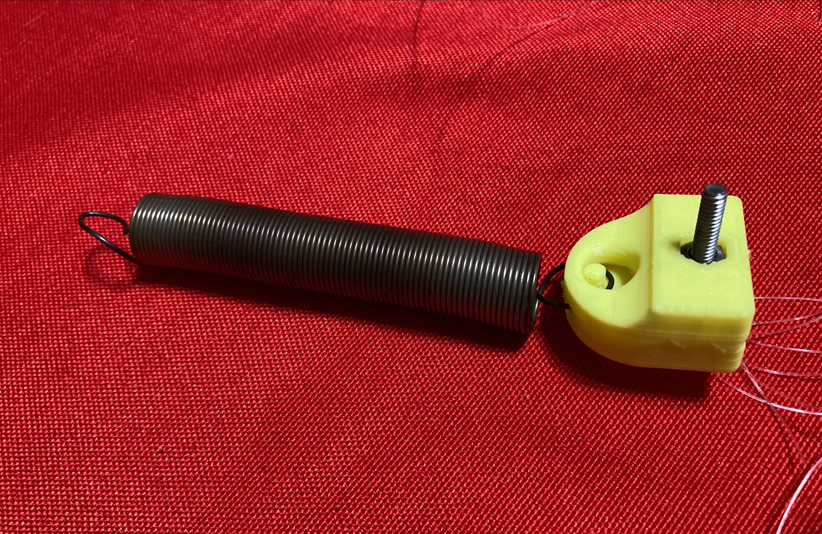
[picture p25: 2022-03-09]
Pictures/Ensamble/7.png

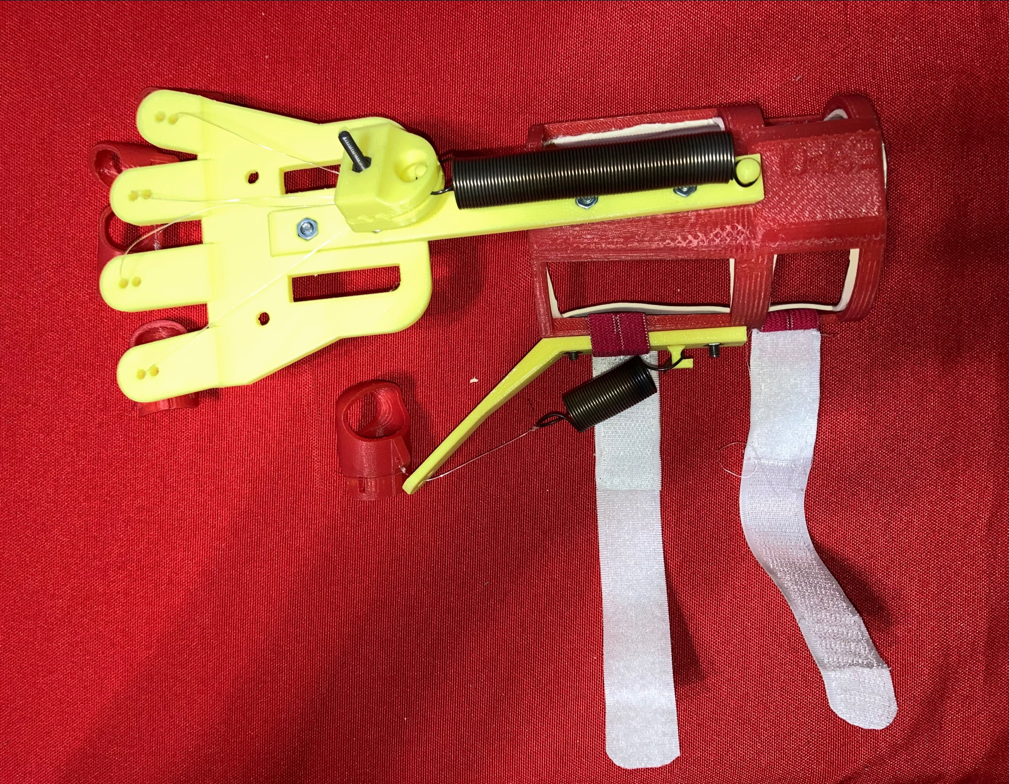
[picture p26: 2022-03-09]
Pictures/Ensamble/ensamblado al 100.png
